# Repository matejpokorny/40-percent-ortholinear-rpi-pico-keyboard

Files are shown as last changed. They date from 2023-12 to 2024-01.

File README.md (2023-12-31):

# 3D printed 40 percent ortholinear raspberry pi pico based mechanical keyboard

This is a 3D printed 40 percent ortholinear mechanical keyboard powered by Raspberry pi pico. The repository contains
the firmware and tutorial on how to build the keyboard.

If you want to read more about the build, you can find the articles on my blog:

- [Building a custom mechanical keyboard](https://blog.matejpokorny.cz/page/2023-12-20_building-a-custom-mechanical-keyboard/)
- [Another custom mechanical keyboard](https://blog.matejpokorny.cz/page/2023-12-31_another-custom-mechanical-keyboard/)

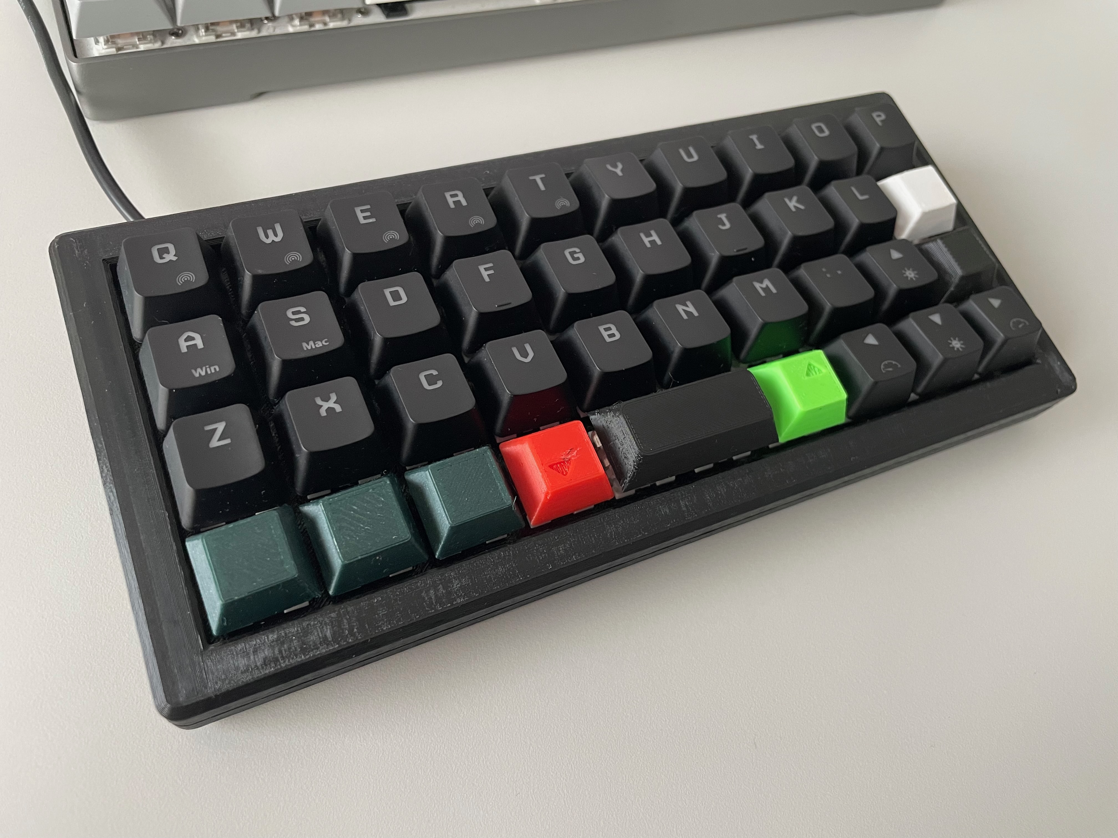
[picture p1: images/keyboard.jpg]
keyboard


*\* When the heat inserted threaded inserts arrive, the zip ties will be replaced with screws.*

## The keymaps

The firmware currently contains 3 layers - the default layer, a control layer
and a symbol layer.

### Default layer

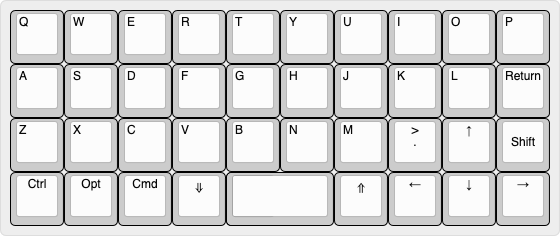
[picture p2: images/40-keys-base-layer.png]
default layer


### Control layer

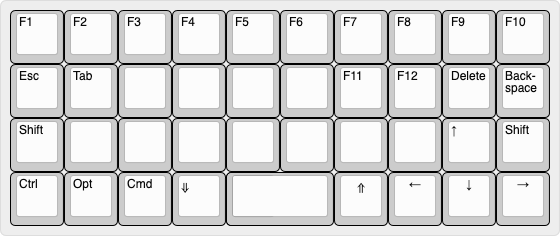
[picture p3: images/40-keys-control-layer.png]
control layer


### Symbol layer

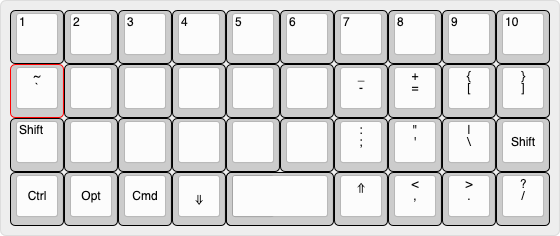
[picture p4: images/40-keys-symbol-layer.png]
symbol layer


## You will need

- 3D printer
- Raspberry Pi Pico
- 40 Cherry MX compatible switches
- 40 keycaps (can be also printed if you want to)
- 40 1N4148 diodes
- some wire
- soldering iron
- a lot of patience

*Tip: if you are cheap like me, you can harvest most of the parts from a cheap second hand mechanical keyboard*

## Build

1. Print the case from  `https://www.printables.com/model/345568-fortyorty`

*The printed parts in the photos are the unfinished prototype later replaced with the model mentioned above.*

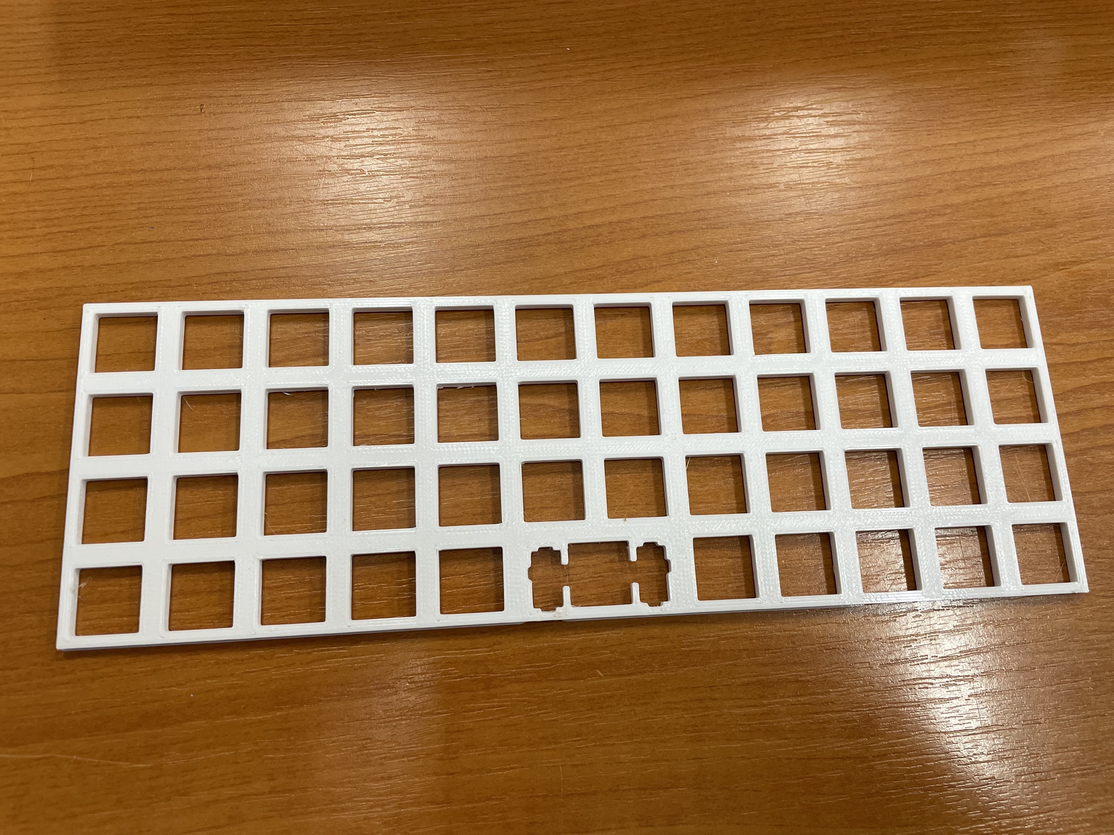
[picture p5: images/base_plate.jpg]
base_plate


2. Assemble all the switches and stabilizer to the base plate

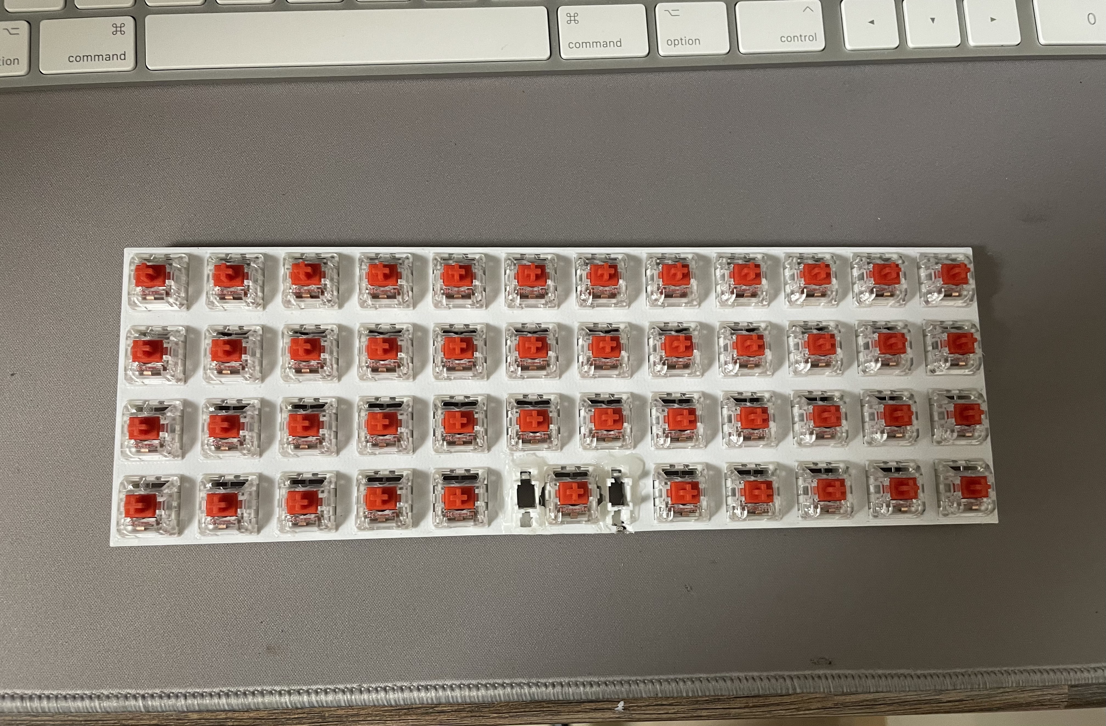
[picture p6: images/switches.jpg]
switches


*I did not use the stabilizers in the end, as the 2U spacebar works just fine without them.*

3. Solder diodes to the switches and connect them in a row as shown in picture below.

- You can also use another wire to connect the diodes in a row instead of connecting them directly.

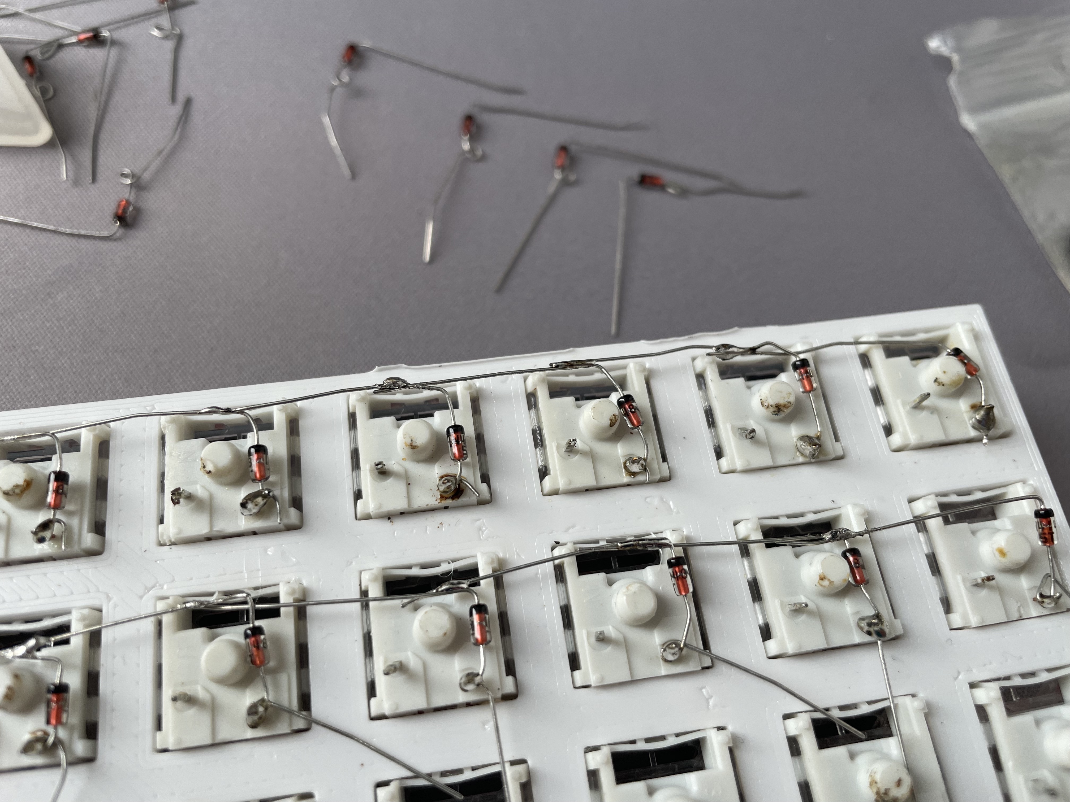
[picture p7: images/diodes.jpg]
diodes


4. Solder wires to the rows of diodes and route them to one place

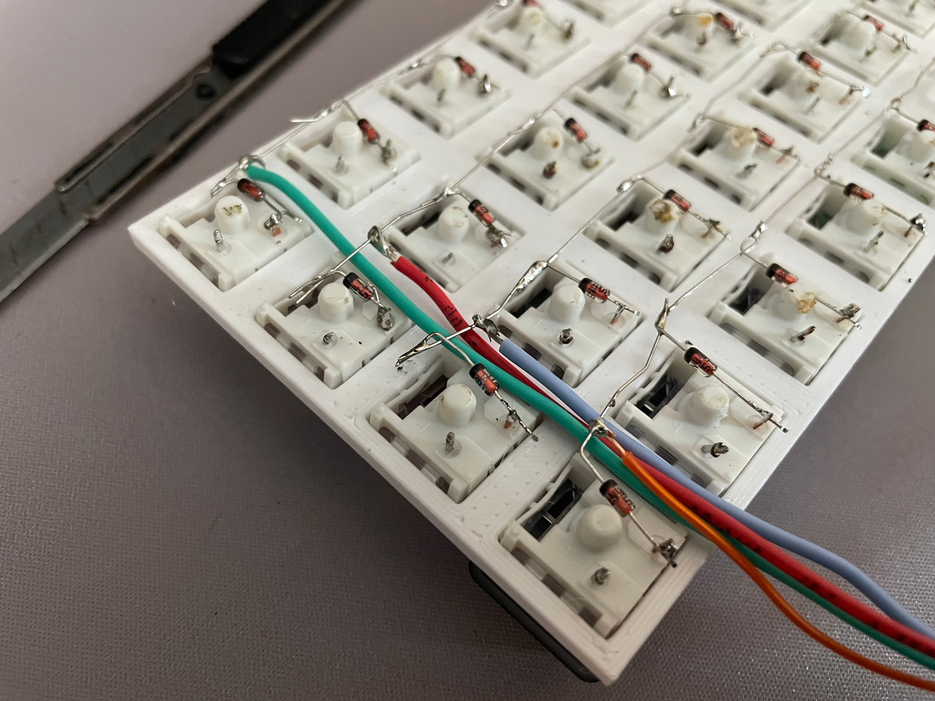
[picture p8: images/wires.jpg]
wires


5. Solder wires to the switches in columns as shown in picture below

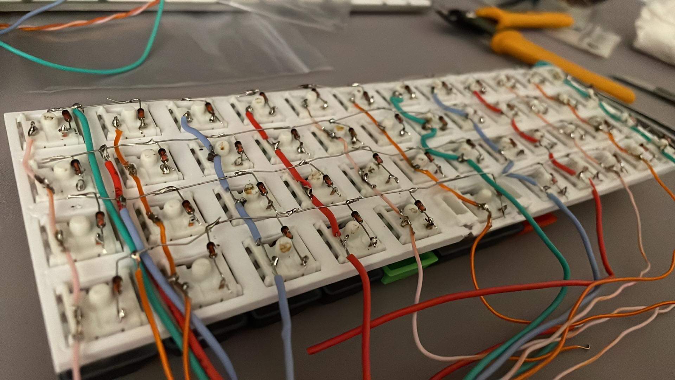
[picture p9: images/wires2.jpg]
wires


6. Choose your GPIO pins on the pico based on your firmware in `pins.py` and solder the wires to the pico

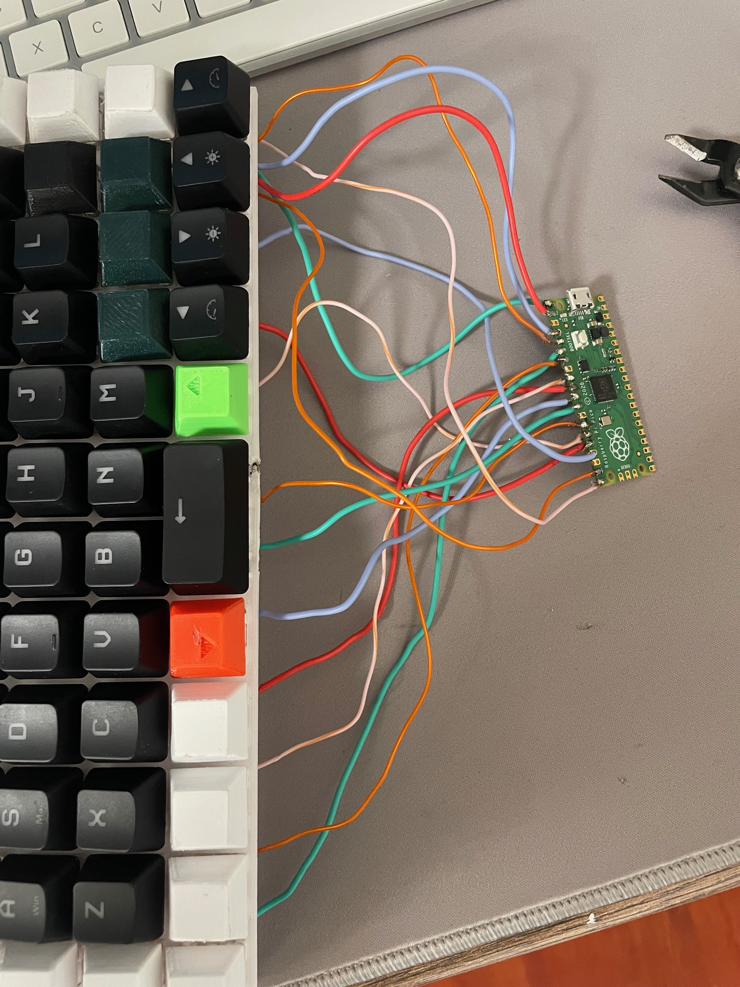
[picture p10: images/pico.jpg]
pico


7. Carefully put the pico inside the keyboard.

- I wrapped the pico in electrical tape to prevent short circuits inside the keyboard.

*Currently in its second generation, the case still does not fit correctly, I modified the second prototype with
side cutters and the case works with zip ties. If I get around to another model and print, I will update this repo.*

## Flashing the firmware

1. Install circutpython on your pico
2. Copy the `adafruit_hid` folder to the `lib` folder on pico.
3. Modify your keymaps in `keymaps.py`
4. Copy the `keymaps.py`, `pins.py` and `code.py` files to the pico.
5. When you are done testing your firmware, you can copy the file called `boot.py` to your pico to prevent it appearing
   as a usb drive on your pc.

## Sources

- Firmware is based on this tutorial: https://learn.adafruit.com/diy-pico-mechanical-keyboard-with-fritzing-circuitpython/code-the-pico-keyboard
- I ended up using this model for the keyboard body instead creating my own: https://www.printables.com/model/345568-fortyorty

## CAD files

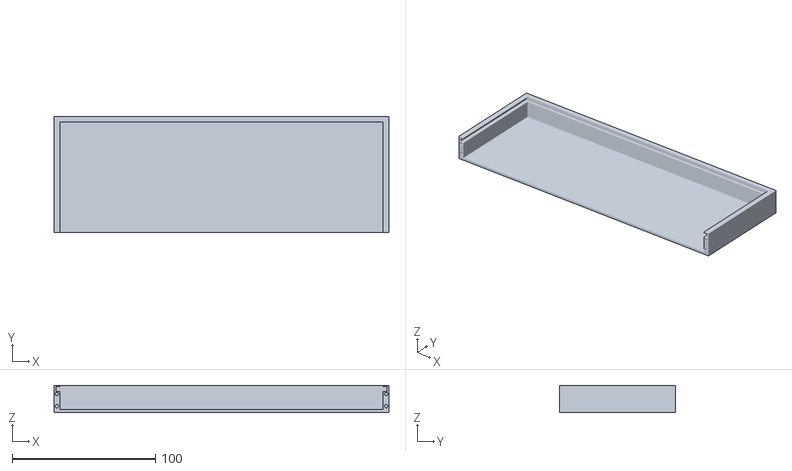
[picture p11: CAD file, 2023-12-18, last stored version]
parts/main_keyboard_body.stl
234.0 x 81.0 x 19.0

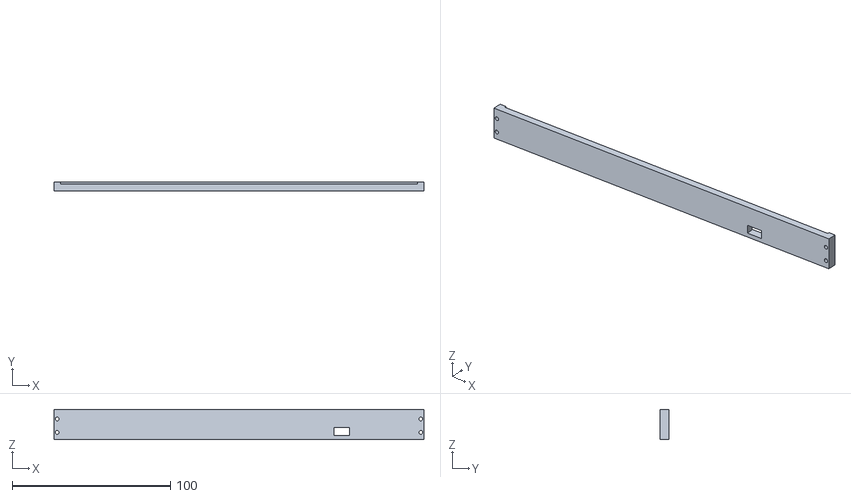
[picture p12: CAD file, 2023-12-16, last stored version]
parts/keyboard_body_cover.stl
234.0 x 5.50 x 19.0

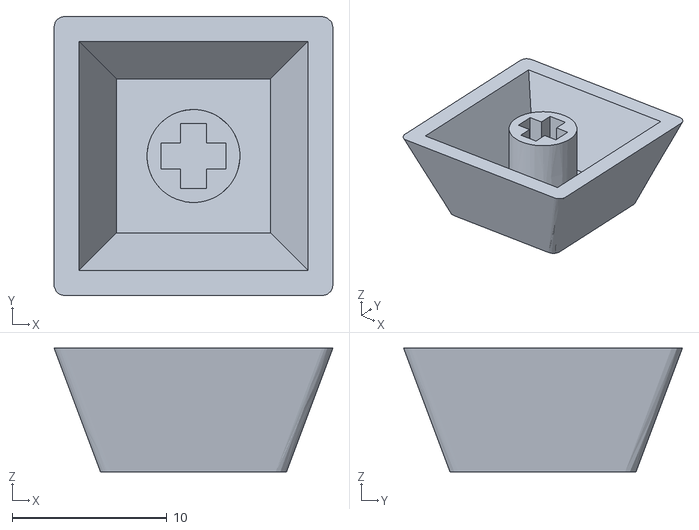
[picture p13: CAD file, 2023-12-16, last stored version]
parts/keycap-layer.stl
18.0 x 18.0 x 8.00

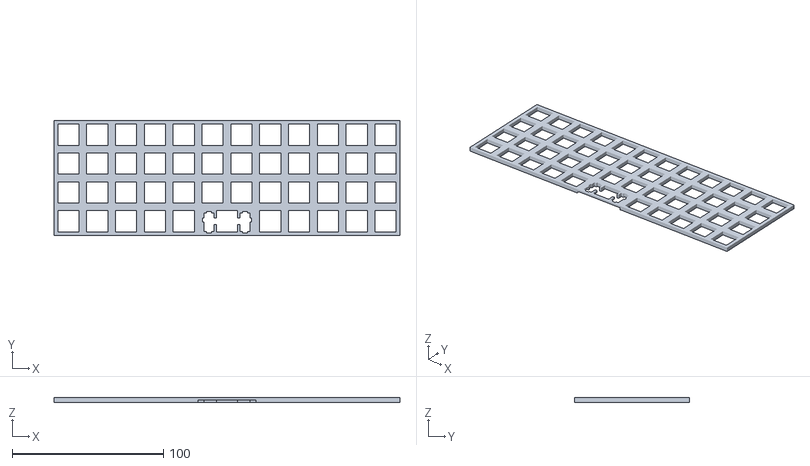
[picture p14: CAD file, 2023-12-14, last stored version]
parts/base_plate.stl
228.6 x 76.2 x 3.00

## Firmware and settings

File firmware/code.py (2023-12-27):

import time
from digitalio import DigitalInOut, Direction, Pull
import usb_hid
from adafruit_hid.keyboard import Keyboard
from adafruit_hid.consumer_control import ConsumerControl

from keymaps import keymap, KEY, MEDIA, LAYER
from pins import row_pins, col_pins

kbd = Keyboard(usb_hid.devices)
cc = ConsumerControl(usb_hid.devices)

input_rows = []
for i in range(len(row_pins)):
    row = DigitalInOut(row_pins[i])
    row.direction = Direction.INPUT
    row.pull = Pull.DOWN
    input_rows.append(row)

output_cols = []
for i in range(len(col_pins)):
    col = DigitalInOut(col_pins[i])
    col.direction = Direction.OUTPUT
    output_cols.append(col)

switch_state = {
    0: [0, 0, 0, 0],
    1: [0, 0, 0, 0],
    2: [0, 0, 0, 0],
    3: [0, 0, 0, 0],
    4: [0, 0, 0, 0],
    5: [0, 0, 0, 0],
    6: [0, 0, 0, 0],
    7: [0, 0, 0, 0],
    8: [0, 0, 0, 0],
    9: [0, 0, 0, 0],
}

active_layer = 0

def press_key(col, button):
    global active_layer
    print(f"Pressed col {col} and row {button} - {keymap[active_layer][button][col][2]}")
    try:
        if keymap[active_layer][button][col][0] == KEY:
            kbd.press(keymap[active_layer][button][col][1])
        elif keymap[active_layer][button][col][0] == MEDIA:
            cc.send(keymap[active_layer][button][col][1])
        elif keymap[active_layer][button][col][0] == LAYER:
            active_layer = keymap[active_layer][button][col][1]
            print(f"Switching to layer {active_layer}")
    except ValueError:  # deals w six key limit
        pass
    switch_state[col][button] = 1


def release_key(col, button):
    global active_layer
    print(f"Released col {col} and row {button} - {keymap[active_layer][button][col][2]}")
    try:
        if keymap[active_layer][button][col][0] == KEY:
            kbd.release(keymap[active_layer][button][col][1])
        if keymap[active_layer][button][col][0] == LAYER:
            active_layer = 0
            print(f"Switching to layer {active_layer}")

    except ValueError:
        pass
    switch_state[col][button] = 0


while True:
    # activate 1 column at a time
    for col in range(len(col_pins)):
        output_cols[col].value = True
        # wait for output to settle
        time.sleep(0.005)

        # read buttons in column
        for button in range(len(row_pins)):
            if switch_state[col][button] == 0:
                if input_rows[button].value:
                    press_key(col, button)

            if switch_state[col][button] == 1:
                if not input_rows[button].value:
                    release_key(col, button)

        # deactivate column
        output_cols[col].value = False

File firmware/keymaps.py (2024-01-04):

from adafruit_hid.keycode import Keycode

MEDIA = 1
KEY = 2
LAYER = 3
NONE = 3

EMPTY_ROW = {
    0: (NONE, 0, "None"),
    1: (NONE, 0, "None"),
    2: (NONE, 0, "None"),
    3: (NONE, 0, "None"),
    4: (NONE, 0, "None"),
    5: (NONE, 0, "None"),
    6: (NONE, 0, "None"),
    7: (NONE, 0, "None"),
    8: (NONE, 0, "None"),
    9: (NONE, 0, "None"),
}

# format is [layer_number][row]{[(type, code, name)]}
keymap = [
    # layer 0
    {
        0: {
            9: (KEY, Keycode.Q, "Q"),
            8: (KEY, Keycode.W, "W"),
            7: (KEY, Keycode.E, "E"),
            6: (KEY, Keycode.R, "R"),
            5: (KEY, Keycode.T, "T"),
            4: (KEY, Keycode.Y, "Y"),
            3: (KEY, Keycode.U, "U"),
            2: (KEY, Keycode.I, "I"),
            1: (KEY, Keycode.O, "O"),
            0: (KEY, Keycode.P, "P"),
        },
        1: {
            9: (KEY, Keycode.A, "A"),
            8: (KEY, Keycode.S, "S"),
            7: (KEY, Keycode.D, "D"),
            6: (KEY, Keycode.F, "F"),
            5: (KEY, Keycode.G, "G"),
            4: (KEY, Keycode.H, "H"),
            3: (KEY, Keycode.J, "J"),
            2: (KEY, Keycode.K, "K"),
            1: (KEY, Keycode.L, "L"),
            0: (KEY, Keycode.ENTER, "Enter"),
        },
        2: {
            9: (KEY, Keycode.Z, "Z"),
            8: (KEY, Keycode.X, "X"),
            7: (KEY, Keycode.C, "C"),
            6: (KEY, Keycode.V, "V"),
            5: (KEY, Keycode.B, "B"),
            4: (KEY, Keycode.N, "N"),
            3: (KEY, Keycode.M, "M"),
            2: (KEY, Keycode.PERIOD, "."),
            1: (KEY, Keycode.UP_ARROW, "Up Arrow"),
            0: (KEY, Keycode.RIGHT_SHIFT, "Shift"),
        },
        3: {
            9: (KEY, Keycode.LEFT_CONTROL, "Ctrl"),
            8: (KEY, Keycode.LEFT_ALT, "Alt"),
            7: (KEY, Keycode.COMMAND, "Cmd"),
            6: (LAYER, 1, "Layer 1"),
            5: (KEY, Keycode.SPACEBAR, "Space"),
            4: (NONE, 0, "None"),
            3: (LAYER, 2, "Layer 2"),
            2: (KEY, Keycode.LEFT_ARROW, "Left Arrow"),
            1: (KEY, Keycode.DOWN_ARROW, "Down Arrow"),
            0: (KEY, Keycode.RIGHT_ARROW, "Right Arrow"),
        },
    },
    # layer 1
    {
        0: {
            9: (KEY, Keycode.F1, "F1"),
            8: (KEY, Keycode.F2, "F2"),
            7: (KEY, Keycode.F3, "F3"),
            6: (KEY, Keycode.F4, "F4"),
            5: (KEY, Keycode.F5, "F5"),
            4: (KEY, Keycode.F6, "F6"),
            3: (KEY, Keycode.F7, "F7"),
            2: (KEY, Keycode.F8, "F8"),
            1: (KEY, Keycode.F9, "F9"),
            0: (KEY, Keycode.F10, "F10"),
        },
        1: {
            9: (KEY, Keycode.ESCAPE, "Esc"),
            8: (KEY, Keycode.TAB, "Tab"),
            7: (NONE, 0, "None"),
            6: (NONE, 0, "None"),
            5: (NONE, 0, "None"),
            4: (NONE, 0, "None"),
            3: (KEY, Keycode.F11, "F11"),
            2: (KEY, Keycode.F12, "F12"),
            1: (KEY, Keycode.DELETE, "Delete"),
            0: (KEY, Keycode.BACKSPACE, "Backspace"),
        },
        2: {
            9: (KEY, Keycode.LEFT_SHIFT, "Shift"),
            8: (NONE, 0, "None"),
            7: (NONE, 0, "None"),
            6: (NONE, 0, "None"),
            5: (NONE, 0, "None"),
            4: (NONE, 0, "None"),
            3: (NONE, 0, "None"),
            2: (NONE, 0, "None"),
            1: (KEY, Keycode.UP_ARROW, "Up Arrow"),
            0: (KEY, Keycode.RIGHT_SHIFT, "Shift"),
        },
        3: {
            9: (KEY, Keycode.LEFT_CONTROL, "Ctrl"),
            8: (KEY, Keycode.LEFT_ALT, "Alt"),
            7: (KEY, Keycode.COMMAND, "Cmd"),
            6: (LAYER, 1, "Layer 1"),
            5: (KEY, Keycode.SPACEBAR, "Space"),
            4: (NONE, 0, "None"),
            3: (LAYER, 2, "Layer 2"),
            2: (KEY, Keycode.LEFT_ARROW, "Left Arrow"),
            1: (KEY, Keycode.DOWN_ARROW, "Down Arrow"),
            0: (KEY, Keycode.RIGHT_ARROW, "Right Arrow"),
        }
    },
    # layer 2
    {
        0: {
            9: (KEY, Keycode.ONE, "1"),
            8: (KEY, Keycode.TWO, "2"),
            7: (KEY, Keycode.THREE, "3"),
            6: (KEY, Keycode.FOUR, "4"),
            5: (KEY, Keycode.FIVE, "5"),
            4: (KEY, Keycode.SIX, "6"),
            3: (KEY, Keycode.SEVEN, "7"),
            2: (KEY, Keycode.EIGHT, "8"),
            1: (KEY, Keycode.NINE, "9"),
            0: (KEY, Keycode.ZERO, "0"),
        },
        1: {
            9: (KEY, Keycode.GRAVE_ACCENT, "`"),
            8: (NONE, 0, "None"),
            7: (NONE, 0, "None"),
            6: (NONE, 0, "None"),
            5: (NONE, 0, "None"),
            4: (NONE, 0, "None"),
            3: (KEY, Keycode.MINUS, "-"),
            2: (KEY, Keycode.EQUALS, "="),
            1: (KEY, Keycode.LEFT_BRACKET, "["),
            0: (KEY, Keycode.RIGHT_BRACKET, "]"),
        },
        2: {
            9: (KEY, Keycode.LEFT_SHIFT, "Shift"),
            8: (NONE, 0, "None"),
            7: (NONE, 0, "None"),
            6: (NONE, 0, "None"),
            5: (NONE, 0, "None"),
            4: (NONE, 0, "None"),
            3: (KEY, Keycode.SEMICOLON, ";"),
            2: (KEY, Keycode.QUOTE, "'"),
            1: (KEY, Keycode.BACKSLASH, "\\"),
            0: (KEY, Keycode.RIGHT_SHIFT, "Shift"),
        },
        3: {
            9: (KEY, Keycode.LEFT_CONTROL, "Ctrl"),
            8: (KEY, Keycode.LEFT_ALT, "Alt"),
            7: (KEY, Keycode.COMMAND, "Cmd"),
            6: (LAYER, 1, "Layer 1"),
            5: (KEY, Keycode.SPACEBAR, "Space"),
            4: (NONE, 0, "None"),
            3: (LAYER, 2, "Layer 2"),
            2: (KEY, Keycode.COMMA, ","),
            1: (KEY, Keycode.PERIOD, "."),
            0: (KEY, Keycode.FORWARD_SLASH, "/"),
        }
    },
]

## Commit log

2023-12-13 Add base_plate.stl model
    [base_plate.stl]
2023-12-14 Updated baseplate
    [base_plate.stl]
2023-12-14 Firmware for 1 button
2023-12-14 1 button mode works
2023-12-16 add hid libraries
    [keyboard_body_cover.stl, keycap-layer.stl, main_keyboard_body.stl]
2023-12-16 switch to circutpython, as micropython does not do HID
2023-12-16 First button works as HID keyboard
2023-12-17 First firmware prototype
2023-12-17 Fix errors from interpreter
    [code.py, keymaps.py]
2023-12-18 Update readme and new version of keyboard body
    [main_keyboard_body.stl]
2023-12-18 Add layer buttons to all layers
2023-12-18 Fix error after returning from layers
    [keymaps.py]
2023-12-19 Add base plate outline svg
2023-12-27 Update to tutorial only, remove bad stl files
    [base_plate.stl, keyboard_body_cover.stl, keycap-layer.stl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]
2024-01-04 Fix keymaps to match layers in README.md
    [keymaps.py]
